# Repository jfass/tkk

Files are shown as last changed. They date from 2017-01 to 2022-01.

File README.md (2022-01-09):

# ten key keyboard

This is my ten key keyboard. I want to type and mouse anywhere, on any surface, and this seems like a necessary step. After I came up with the layout, someone pointed me towards the [asetniop](http://asetniop.com) layout, but by then this was stuck in my head. In any event, this is my first attempt at building my own keyboard, and I have absolutely no idea what I'm doing. This is based on TristanTrim's [asetniop-keyboard](https://github.com/TristanTrim/asetniop-keyboard), but obviously with two more keys.

Layout ... the bottom row are the physical keys. But, hold any key and it activates the virtual row corresponding to the greek letter in blue; tap any key while still holding, and you get the corresponding key on the virtual row. So, tapping the 't' key gives you a 't'. But holding the 't' key activates the gamma row, so if you then tap your left pinky (the physical 'a' key) you get a minus ('-') character. No idea whether this will allow graceful typing; gotta build it first!

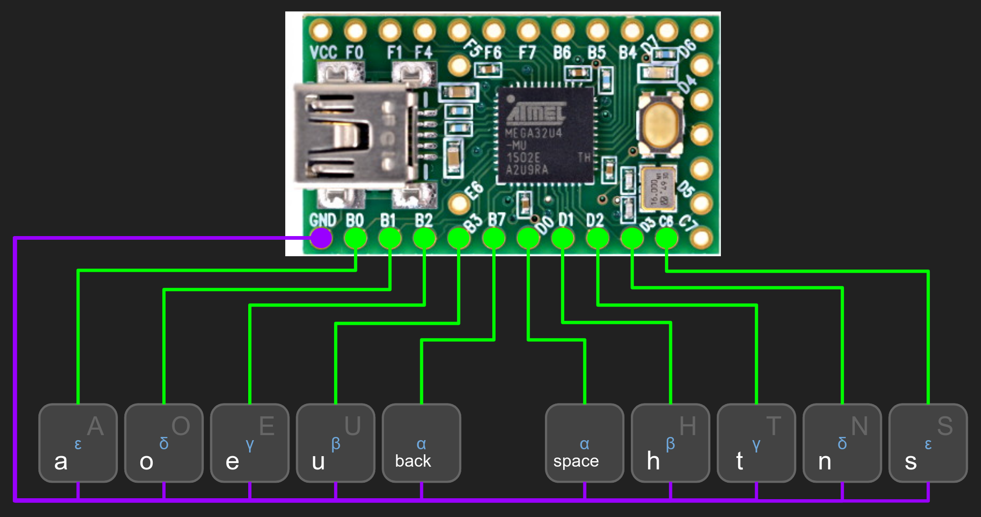
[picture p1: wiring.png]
Wiring
 ... with a Teensy 2.0.

... need to edit below here ...

## Installation
Keys are wired up directly to the pins D0 - D7. There are ways to do this that would save pins, but I like this method because it's easy, and I don't need the extra pins for anything.

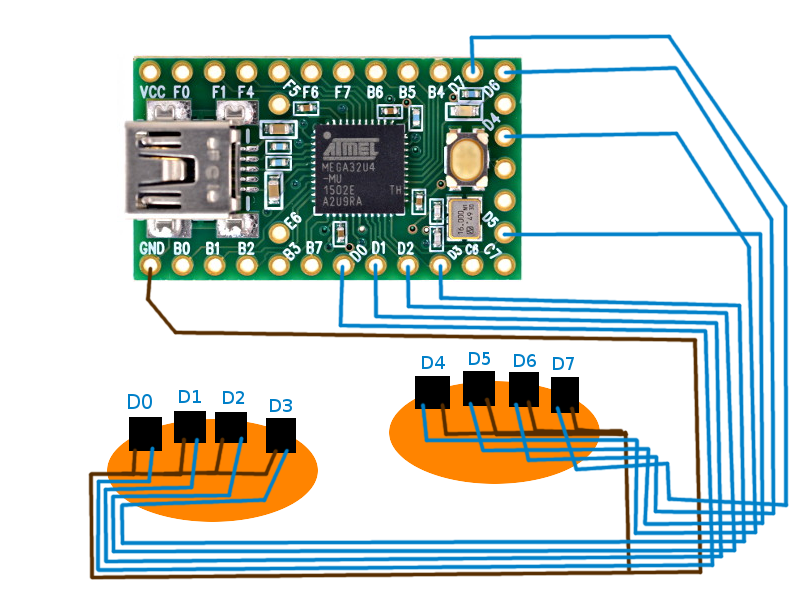
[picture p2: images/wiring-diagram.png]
wiring diagram


If you're on linux like me you may want to use the [bootloader](https://github.com/PaulStoffregen/teensy_loader_cli)

    sudo ./teensy_loader_cli/teensy_loader_cli --mcu=atmega32u4 asetniop.hex -w

Otherwise you'll have to flash the firmware some other way. Message me if you don't know how and I'll try to help you out.

## Bill of materials

 - [A teensyduino 2.0 board.](https://www.pjrc.com/store/teensy.html)
 - A 3D printed copy of each of the [.stl files.](https://github.com/TristanTrim/asetniop-keyboard/tree/master/printed_parts)
 - [8 Keyswitches](https://mechanicalkeyboards.com/shop/index.php?l=product_detail&p=708)
 - [8 Keycaps](http://www.wasdkeyboards.com/index.php/products/blank-keycap-singles/row-2-size-1x1-cherry-mx-keycap.html) (if you're not printing them)
 - wire and solder tools.
 - M3 nuts and bolts for the case.

## Typing guide

If you want to start learning about typing with this style of chorded keyboard, you can use the asetniop [online demo](http://asetniop.com/try/tablet/) to start learning asetniop in your web browser using your qwerty keyboard. This way you can find out what its like to type with a chorded keyboard without needing to do anything radical like building a keyboard.

There are a number of additions to the asetniop chords to expand this project into a more general keyboard. Also my keyboard only has eight keys, so doesn't use the thumbs at all. I'll explain below.

For the purpose of this guide I'm representing chords with a series of '.'s and '#'s. The '#'s represent a key being pressed down, and the '.'s a key left unpressed. Read from left to right the keys represented are the left pinky key through to the right pinky key.

### Numbers
The numbers all use .### on the left as somewhat of a prefix, and then follows a binary sequence from 0 to 9.

    .### .... : 0
    .### ...# : 1
    .### ..#. : 2
    .### ..## : 3
    .### .#.. : 4
    .### .#.# : 5
    .### .##. : 6
    .### .### : 7
    .### #... : 8
    .### #..# : 9

### Arrow keys
Like with the numbers the arrow keys use a 'prefix'. They all start with the 'w' key; ##..

    ##.. ...# : up
    ##.. ..## : down
    ##.. ..#. : left
    ##.. .#.. : right

### Non-alphanumeric
The non-alphanumeric keys were some of the first I wanted for interacting with my computer. The way the 'ctrl', 'shift', 'alt', and 'mod/window' keys work is that you press the chord, and then it is applied to the next chord that is pressed. For example, to get a '?' you would press #### ..#. and then press #... ...#

    #### ...# : ctrl
    #### ..#. : shift
    #### .#.. : alt
    #### #... : mod/window
    .... #### : space
    ...# #### : enter
    ###. .... : tab
    #### .... : esc

The rest of the keys may be a bit confusing, because I didn't add chords for anything that would normally be accessed by pressing shift+'some key'. So, for example, to use a '!' you need to press the chord for shift followed by the key for 1. because of this it's important to remember where all the symbols are on the qwerty keyboard. (assuming you want to use them.)

Of the rest of the keys, some of them may be in the original asetniop, and others I may have added or changed. I don't really remember which is which, sorry.

    .... ##.# : [
    .... #.## : ]
    #... ...# : /
    #... ..#. : \
    #... #### : `
    ..#. ..#. : -
    ..#. ..## : =
    
## Random nonsense

 - [x] Chord started before previous chord released separation. Now you can press ..#. ...., ..## ...., ..#. ... for "ere". Play around with it.
 - [ ] multibackspace: undo as many keypresses as were sent on the last chord release, for example if you type "ere" when you meant "r" backspace 3 times is useful.
 - [ ] Improved circuit design to use 3 rather than 5 wires to the keys. Then chinsy audio cables could be used!
 - [ ] abandon wired and write this on a bluetooth platform
 - [ ] macro functionality.
 - [ ] saving & dumping macros.
 - [ ] some kinda ml for separating chords, cause I type "ere" a lot, but not "sds" so much.

blah blah blah

I'd like to add the rest of the keys on a standard keyboard, and maybe some special function keys, but I'm not sure when I'll get around to it.

Further down the line I would like to experiment with adding joystick / mouse functionality, and building a wireless pair.

Or abandoning this and making a pair that maps the fingers onto a ternary, rather than binary, system. You know, for the 3 positions ^ 10 fingers = 59049 chords, rather than the 2 positions ^ 8 fingers = 256 chords availiable on my current system. If I assume 12 axes because the thumbs move in two axes so nicely that gives me: 3 positions ^ 12 axes = 531441. That's 3 positions ^ 6 axes = 729 chords on one hand! The trouble then would never be space, but figuring out how to organise all the chords. Ok, it would probably still be space at some point, because who wants to be stuck with a vocabulary of just over half a million. So lame right?

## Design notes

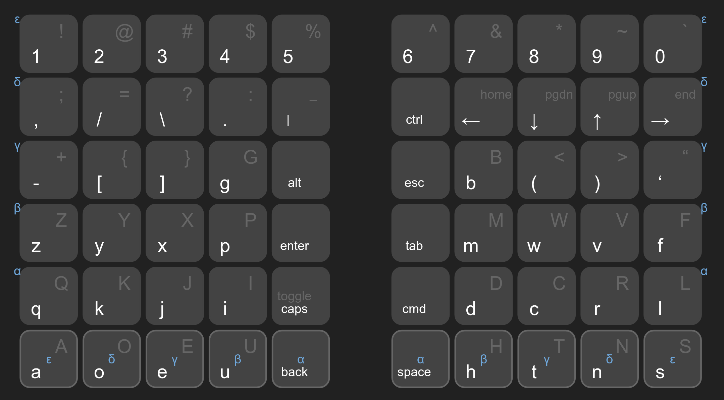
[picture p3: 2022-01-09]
layout.png

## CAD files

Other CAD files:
asetniop_render.blend

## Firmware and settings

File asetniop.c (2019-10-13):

/* This is the asetniop teensy code.
 * It implements a version of asetniop on a teensy
 * Based on the teensy keyboard example:
 *
 * Keyboard example with debug channel, for Teensy USB Development Board
 * http://www.pjrc.com/teensy/usb_keyboard.html
 * Copyright (c) 2008 PJRC.COM, LLC
 * 
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
 * THE SOFTWARE IS PROVIDED "AS IS", WITHOUT WARRANTY OF ANY KIND, EXPRESS OR
 * IMPLIED, INCLUDING BUT NOT LIMITED TO THE WARRANTIES OF MERCHANTABILITY,
 * FITNESS FOR A PARTICULAR PURPOSE AND NONINFRINGEMENT. IN NO EVENT SHALL THE
 * AUTHORS OR COPYRIGHT HOLDERS BE LIABLE FOR ANY CLAIM, DAMAGES OR OTHER
 * LIABILITY, WHETHER IN AN ACTION OF CONTRACT, TORT OR OTHERWISE, ARISING FROM,
 * OUT OF OR IN CONNECTION WITH THE SOFTWARE OR THE USE OR OTHER DEALINGS IN
 * THE SOFTWARE.
 */

#include <avr/io.h>
#include <avr/pgmspace.h>
#include <avr/interrupt.h>
#include <util/delay.h>
#include "usb_keyboard.h"

#define LED_CONFIG  (DDRD |= (1<<6))
#define LED_ON    (PORTD &= ~(1<<6))
#define LED_OFF    (PORTD |= (1<<6))
#define CPU_PRESCALE(n)  (CLKPR = 0x80, CLKPR = (n))


void zero(void);
void empty(void);
void normal(void);
void meta(void);
void arrow(void);
void page(void);

typedef void (*func)(void);
func keymap_func[6] = {zero, empty, normal, meta, arrow, page};
#define z 0
#define e 1
#define n 2
#define m 3
#define a 4
#define p 5


//128 64 32 16  8 4 2 1
uint8_t modifier_keys[4] =
    {KEY_CTRL,       KEY_SHIFT,       KEY_ALT,       KEY_GUI,       };
uint8_t modifier_key_numbers[4] =
    {128+64+32+16+1, 128+64+32+16+2, 128+64+32+16+4, 128+64+32+16+8,};
uint8_t modifier_chord_id;

// So I'm trying to make this array of chords kinda readable
// It's broken up into sixteen sections, each one has a set of all the
// chords formed with the same pattern on the left hand, and goes through
// the binary sequency of patterns for the right hand.
// That is to say, for each set the chord pattern goes like:
//    xx xx  .. .. ,  xx xx  .. .# ,  xx xx  .. #. ,  xx xx  .. ## ,
//    xx xx  .# .. ,  xx xx  .# .# ,  xx xx  .# #. ,  xx xx  .# ##  ,
//    xx xx  #. .. ,  xx xx  #. .# ,  xx xx  #. #. ,  xx xx  #. ## ,
//    xx xx  ## .. ,  xx xx  ## .# ,  xx xx  ## #. ,  xx xx  ## ##  ,
// Each entry consists of a function for how that chord should
// be interpreted, and a chord value that represents what that
// chord should send as a key to the computer.
// Like:    [function, value]
// So for example, the chord '.. ..  .# .#' represents the letter 'k'
// when that key is pressed, it is interpretted as a regular keypress
// so it gets the function 'normal' shorthanded to 'n'.
// Like:    [n,KEY_K        ] 
// All the empty space is to maintain a nice readable grid.


uint8_t key_map[256][2] = {
// .. ..    0
    {z,0            },{n,KEY_P        },{n,KEY_O        },{n,KEY_SEMICOLON},    // 0   1   2   3
    {n,KEY_I        },{n,KEY_K        },{n,KEY_L        },{e,0            },    // 4   5   6   7
    {n,KEY_N        },{n,KEY_M        },{n,KEY_U        },{n,KEY_RIGHT_BRACE},    // 8   9   10   11
    {n,KEY_H        },{n,KEY_LEFT_BRACE},{e,0           },{n,KEY_SPACE    },    // 12   13   14   15
// .. .#    16
    {n,KEY_T        },{n,KEY_BACKSPACE},{n,KEY_G        },{e,0            },    // 16   17   18   19
    {n,KEY_V        },{e,0            },{e,0            },{e,0            },    // 20   21   22   23
    {n,KEY_B        },{e,0            },{e,0            },{e,0            },    // 24   25   26   27
    {e,0            },{e,0            },{e,0            },{n,KEY_ENTER    },    // 28   29   30   31
// .. #.    32
    {n,KEY_E        },{n,KEY_QUOTE    },{n,KEY_MINUS    },{n,KEY_EQUAL    },    // 32   33   34   35
    {n,KEY_COMMA    },{e,0            },{e,0            },{e,0            },    // 36   37   38   39
    {n,KEY_Y        },{e,0            },{e,0            },{e,0            },    // 40   41   42   43
    {e,0            },{e,0            },{e,0            },{e,0            },    // 44   45   46   47
// .. ##    48
    {n,KEY_R        },{e,0            },{e,0            },{e,0            },    // 48   49   50   51
    {e,0            },{e,0            },{e,0            },{e,0            },    // 52   53   54   55
    {e,0            },{e,0            },{e,0            },{e,0            },    // 56   57   58   59
    {e,0            },{e,0            },{e,0            },{e,0            },    // 60   61   62   63
// .# ..    64
    {n,KEY_S        },{n,KEY_SPACE    },{n,KEY_PERIOD   },{e,0            },    // 64   65   66   67
    {n,KEY_Z        },{e,0            },{e,0            },{e,0            },    // 68   69   70   71
    {n,KEY_J        },{e,0            },{e,0            },{e,0            },    // 72   73   74   75
    {e,0            },{e,0            },{e,0            },{e,0            },    // 76   77   78   79
// .# .#    80
    {n,KEY_C        },{e,0            },{e,0            },{e,0            },    // 80   81   82   83
    {e,0            },{e,0            },{e,0            },{e,0            },    // 84   85   86   87
    {e,0            },{e,0            },{m, 0           },{e,0            },    // 88   89   90   91
    {e,0            },{e,0            },{e,0            },{e,0            },    // 92   93   94   95
// .# #.    96
    {n,KEY_D        },{e,0            },{e,0            },{e,0            },    // 96   97   98   99
    {e,0            },{e,0            },{e,0            },{e,0            },    // 100   101   102   103
    {e,0            },{e,0            },{e,0            },{e,0            },    // 104   105   106   107
    {e,0            },{e,0            },{e,0            },{e,0            },    // 108   109   110   111
// .# ##    112
    {n,KEY_0        },{n,KEY_1        },{n,KEY_2        },{n,KEY_3        },    // 112   113   114   115
    {n,KEY_4        },{n,KEY_5        },{n,KEY_6        },{n,KEY_7        },    // 116   117   118   119
    {n,KEY_8        },{n,KEY_9        },{e,0            },{e,0            },    // 120   121   122   123
    {e,0            },{e,0            },{e,0            },{e,0            },    // 124   125   126   127
// #. ..    128
    {n,KEY_A        },{n,KEY_SLASH    },{n,KEY_BACKSLASH},{e,0            },    // 128   129   130   131
    {e,0            },{e,0            },{e,0            },{e,0            },    // 132   133   134   135
    {n,KEY_Q        },{e,0            },{e,0            },{e,0            },    // 136   137   138   139
    {e,0            },{e,0            },{e,0            },{n,KEY_TILDE    },    // 140   141   142   143
// #. .#    144
    {n,KEY_F        },{e,0            },{e,0            },{e,0            },    // 144   145   146   147
    {e,0            },{e,0            },{e,0            },{e,0            },    // 148   149   150   151
    {e,0            },{e,0            },{e,0            },{e,0            },    // 152   153   154   155
    {e,0            },{e,0            },{e,0            },{e,0            },    // 156   157   158   159
// #. #.    160
    {n,KEY_X        },{e,0            },{e,0            },{e,0            },    // 160   161   162   163
    {e,0            },{n, 0           },{e,0            },{e,0            },    // 164   165   166   167
    {e,0            },{e,0            },{e,0            },{e,0            },    // 168   169   170   171
    {e,0            },{e,0            },{e,0            },{e,0            },    // 172   173   174   175
// #. ##    176
    {e,0            },{e,0            },{e,0            },{e,0            },    // 176   177   178   179
    {e,0            },{e,0            },{e,0            },{e,0            },    // 180   181   182   183
    {e,0            },{e,0            },{e,0            },{e,0            },    // 184   185   186   187
    {e,0            },{e,0            },{e,0            },{e,0            },    // 188   189   190   191
// ## ..    192
    {n,KEY_W        },{a,KEY_RIGHT    },{a,KEY_UP       },{e,0            },    // 192   193   194   195
    {a,KEY_DOWN     },{e,0            },{e,0            },{e,0            },    // 196   197   198   199
    {a,KEY_LEFT     },{e,0            },{e,0            },{e,0            },    // 200   201   202   203
    {e,0            },{e,0            },{e,0            },{e,0            },    // 204   205   206   207
// ## .#    208
    {e,0            },{e,0            },{e,0            },{e,0            },    // 208   209   210   211
    {e,0            },{e,0            },{e,0            },{e,0            },    // 212   213   214   215
    {e,0            },{e,0            },{e,0            },{e,0            },    // 216   217   218   219
    {e,0            },{e,0            },{e,0            },{e,0            },    // 220   221   222   223
// ## #.    224
    {n,KEY_TAB      },{p,KEY_END      },{p,KEY_PAGE_UP  },{e,0            },    // 224   225   226   227
    {p,KEY_PAGE_DOWN},{e,0            },{e,0            },{e,0            },    // 228   229   230   231
    {p,KEY_HOME     },{e,0            },{e,0            },{e,0            },    // 232   233   234   235
    {e,0            },{e,0            },{e,0            },{e,0            },    // 236   237   238   239
// ## ##    240  These are mostly all modifier keys. They are handled elsewhere, but still called with n
    {n,KEY_ESC      },{n,0            },{n,0            },{n,0            },    // 240   241   242   243
    {n,0            },{n,0            },{n,0            },{n,0            },    // 244   245   246   247
    {n,0            },{n,0            },{n,0            },{n,0            },    // 248   249   250   251
    {n,0            },{n,0            },{n,0            },{e,0            }     // 252   253   254   255
};

uint8_t realtime_index;
uint8_t realtime_map[2][4] =
{
    {KEY_LEFT       ,KEY_DOWN        ,KEY_UP          ,KEY_RIGHT       },
    {KEY_END        ,KEY_PAGE_DOWN   ,KEY_PAGE_UP     ,KEY_HOME        }
};

void read(void);
void keydown(void);
void keyup(void);
void keysend(void);

void dump_fifo(void);
void clear_fifo(void);
void debug_dump(void);
void realtime(void);
void keyhold(void);
void modpress(uint8_t modchord);
void send(int send_id);

uint8_t d, prev_d, mask, chord_id, prev_chord_id, pressed, modifier_pressed,timer;
uint8_t chord_keys[8];//={0,0,0,0,0,0,0,0};

uint8_t fifo_index;
uint16_t fifo[64][2];
uint16_t longest;
int chord_accept_numer = 1;
int chord_accept_denom = 2;

int debug_mode = 0;

uint8_t modkeys;
uint8_t modlocks;

#define keydown_delay  3000
#define min_press_detect  0
#define debounce_delay 300

int main(void)
{
  // Stuff from the original keyboard code for, like, being a keyboard and stuff.

  // set for 16 MHz clock
  CPU_PRESCALE(0);

  // Configure all port B and port D pins as inputs with pullup resistors.
  // See the "Using I/O Pins" page for details.
  // http://www.pjrc.com/teensy/pins.html
  DDRD = 0x00;
  PORTD = 0xFF;

  // Initialize the USB, and then wait for the host to set configuration.
  // If the Teensy is powered without a PC connected to the USB port,
  // this will wait forever.
  usb_init();
  while (!usb_configured()) /* wait */ ;

  // Wait an extra second for the PC's operating system to load drivers
  // and do whatever it does to actually be ready for input
  _delay_ms(1000);


  // And now for the main event!

  while (1) {
    read();
    keymap_func[  key_map[chord_id][0]  ]();
  }
}
///////////////////// we have lost cabin pressure.
//
//    if (((chord_id == 0) && (last_chord_id != 0)) || timer == timeout ) {
//        timer=timeout-timebetween;
//
//        mask = 1;
//        for (i=0; i<4; i++) {
//            if (modifier_key_numbers[i] == last_chord_id) {
//                modifier_pressed = 1;
//                if ((modifier_chord_id & mask) == 0 ) {
//                    modifier_chord_id += 1<<i;
//                }
//            }
//            mask = mask << 1;
//        }
//        if (modifier_pressed == 0) {
//            usb_keyboard_press(key_map[last_chord_id][1],modifier_chord_id);
//            modifier_chord_id = 0;
//        }
//        last_chord_id = 0;
//        modifier_pressed = 0;
//    }
//    if (chord_id > last_chord_id) {
//        last_chord_id = chord_id;
//    }
//
//    // now the current pins will be the previous, and
//    // wait a short delay so we're not highly sensitive
//    // to mechanical "bounce".
//    _delay_ms(2);
////////////////////////////// cabin pressure stabalized.


// keymap functions:

void zero(void){
  // When keys have been pressed and we are at zero
  // we know it's time to send those pressed keys!
  if(pressed){
    if(debug_mode){
      debug_dump();
    }
    dump_fifo();
  }
}
void empty(void){
  // As if we even care what happens when undefined
  // keys are pressed!
}
void normal(void){
  if(!pressed){
    fifo[fifo_index][0] = chord_id;
    pressed=1;
  }else{
    if(fifo[fifo_index][0] == chord_id){
      if(fifo[fifo_index][1] > keydown_delay){
        keyhold();
      }else{
        if(++fifo[fifo_index][1] > longest){
          longest = fifo[fifo_index][1];
        }
      }
    }else{
      fifo_index++;
      fifo[fifo_index][0] = chord_id;
    }
  }
}
void meta(void){
  while(1){
    read();
    if(chord_id != 90)
      break;
  }
  debug_mode = !debug_mode;
  if(debug_mode){
    usb_keyboard_press(KEY_D,2);
    usb_keyboard_press(KEY_E,2);
    usb_keyboard_press(KEY_B,2);
    usb_keyboard_press(KEY_U,2);
    usb_keyboard_press(KEY_G,2);
    usb_keyboard_press(KEY_ENTER,0);
  }else{
    usb_keyboard_press(KEY_B,2);
    usb_keyboard_press(KEY_A,2);
    usb_keyboard_press(KEY_C,2);
    usb_keyboard_press(KEY_K,2);
    usb_keyboard_press(KEY_SPACE,2);
    usb_keyboard_press(KEY_T,2);
    usb_keyboard_press(KEY_O,2);
    usb_keyboard_press(KEY_SPACE,2);
    usb_keyboard_press(KEY_N,2);
    usb_keyboard_press(KEY_O,2);
    usb_keyboard_press(KEY_R,2);
    usb_keyboard_press(KEY_M,2);
    usb_keyboard_press(KEY_A,2);
    usb_keyboard_press(KEY_L,2);
    usb_keyboard_press(KEY_SPACE,2);
    usb_keyboard_press(KEY_MINUS ,0);
    usb_keyboard_press(KEY_SPACE,2);
    usb_keyboard_press(KEY_N,2);
    usb_keyboard_press(KEY_O,2);
    usb_keyboard_press(KEY_T,2);
    usb_keyboard_press(KEY_H,2);
    usb_keyboard_press(KEY_I,2);
    usb_keyboard_press(KEY_N,2);
    usb_keyboard_press(KEY_G,2);
    usb_keyboard_press(KEY_SPACE,2);
    usb_keyboard_press(KEY_T,2);
    usb_keyboard_press(KEY_O,2);
    usb_keyboard_press(KEY_SPACE,2);
    usb_keyboard_press(KEY_S,2);
    usb_keyboard_press(KEY_E,2);
    usb_keyboard_press(KEY_E,2);
    usb_keyboard_press(KEY_SPACE,2);
    usb_keyboard_press(KEY_H,2);
    usb_keyboard_press(KEY_E,2);
    usb_keyboard_press(KEY_R,2);
    usb_keyboard_press(KEY_E,2);
    usb_keyboard_press(KEY_ENTER,0);
  }
}
void arrow(void){
  realtime_index = 0;
  realtime();
}
void page(void){
  realtime_index = 1;
  realtime();
}

// hardware functions:

void read(void){
  // read all port D pins
  d = PIND;
  int i=0;
  while(1){// debouncing loop
    prev_d = d;
    d = PIND;
    if(d==prev_d)
      i++;
    else
      i=0;
    if(i==debounce_delay)
      break;
  } 
  chord_id = ~d;
  mask = 1;// sweepy sweepy sweep my byte!
  for (int i=0; i<8; i++) {
    if ((d & mask) == 0)  {
              chord_keys[i] = 1;
          }
    mask = mask << 1;
  }
}
void keydown(void){
}
void keyup(void){
}
void keysend(void){
  usb_keyboard_press(key_map[chord_id][1],modifier_chord_id);
}

// cool functions that I like:
void debug_dump(void){
  usb_keyboard_press(KEY_C,1);            /////////// DEBUGING TOOL, PRINT BASED ON HOW MUCH IT"S PRESSED
  usb_keyboard_press(KEY_C,1);            /////////// DEBUGING TOOL, PRINT BASED ON HOW MUCH IT"S PRESSED
  usb_keyboard_press(KEY_ENTER,0);            /////////// DEBUGING TOOL, PRINT BASED ON HOW MUCH IT"S PRESSED
  usb_keyboard_press(KEY_SPACE,0);            /////////// DEBUGING TOOL, PRINT BASED ON HOW MUCH IT"S PRESSED
  usb_keyboard_press(KEY_COMMA,2);            /////////// DEBUGING TOOL, PRINT BASED ON HOW MUCH IT"S PRESSED
  usb_keyboard_press(KEY_3,0);            /////////// DEBUGING TOOL, PRINT BASED ON HOW MUCH IT"S PRESSED
  usb_keyboard_press(KEY_SPACE,0);            /////////// DEBUGING TOOL, PRINT BASED ON HOW MUCH IT"S PRESSED
  int accept_len = longest*chord_accept_numer/chord_accept_denom;
  for(int i=0; i<=accept_len/20; i++)
    usb_keyboard_press(KEY_EQUAL,0);      /////////// DEBUGING TOOL, PRINT BASED ON HOW MUCH IT"S PRESSED
  for(int i=0; i<=(longest-accept_len)/20; i++)
    usb_keyboard_press(KEY_MINUS,0);      /////////// DEBUGING TOOL, PRINT BASED ON HOW MUCH IT"S PRESSED
  usb_keyboard_press(KEY_C,1);            /////////// DEBUGING TOOL, PRINT BASED ON HOW MUCH IT"S PRESSED
  usb_keyboard_press(KEY_ENTER,0);            /////////// DEBUGING TOOL, PRINT BASED ON HOW MUCH IT"S PRESSED
  for(int i=0; i<=fifo_index; i++){
    if(fifo[i][1] > accept_len){// YES! SEND IT
      usb_keyboard_press(KEY_1,2);
      usb_keyboard_press(KEY_1,2);
      usb_keyboard_press(KEY_1,2);
    }else{  /// NOT ENOUGH SENDAGE
      usb_keyboard_press(KEY_SPACE,0);
      usb_keyboard_press(KEY_SPACE,0);
      usb_keyboard_press(KEY_SPACE,0);
    }
    send(fifo[i][0]);//// ACTUALLY SEND THE DAMNED KEYPRESS
    for(int j =0; j<fifo[i][1]/20;j++)  /////////// DEBUGING TOOL, PRINT BASED ON HOW MUCH IT"S PRESSED
      usb_keyboard_press(KEY_MINUS,0);      /////////// DEBUGING TOOL, PRINT BASED ON HOW MUCH IT"S PRESSED
    usb_keyboard_press(KEY_C,1);            /////////// DEBUGING TOOL, PRINT BASED ON HOW MUCH IT"S PRESSED
    usb_keyboard_press(KEY_ENTER,0);            /////////// DEBUGING TOOL, PRINT BASED ON HOW MUCH IT"S PRESSED
  }
  usb_keyboard_press(KEY_ENTER,0);            /////////// DEBUGING TOOL, PRINT BASED ON HOW MUCH IT"S PRESSED
}
void dump_fifo(void){
  int accept_len = longest*chord_accept_numer/chord_accept_denom;
  for(int i=0; i<=fifo_index; i++){
    if(fifo[i][1] > accept_len){// YES! SEND IT
      send(fifo[i][0]);
    }
    fifo[i][1]=0;
  }
  longest = min_press_detect*2;
  pressed = 0;
  fifo_index = 0;
}
void clear_fifo(void){
  for(int i=0; i<=fifo_index; i++){
    fifo[i][1]=0;
  }
  longest = min_press_detect*2;
  pressed = 0;
  fifo_index = 0;
}
void send(int send_id){
  // send_id is the id of the chord we're gonna send.
  if(send_id>240&&send_id!=255){ // If it's a modifier chord
    if(debug_mode){
      usb_keyboard_press(KEY_M,2);
      usb_keyboard_press(KEY_O,2);
      usb_keyboard_press(KEY_D,2);
    }else{ // Don't send modifier in debug mode. It does things. Bad things.
      modpress(send_id);
    }
  }else if(send_id == 165){// 165 is #.#. .#.# and the clear mod key.
    if(debug_mode){
      usb_keyboard_press(KEY_N,2);
      usb_keyboard_press(KEY_O,2);
      usb_keyboard_press(KEY_M,2);
      usb_keyboard_press(KEY_O,2);
      usb_keyboard_press(KEY_D,2);
    }
    modlocks =  0;
    modkeys = 0;
  }else{
    usb_keyboard_press(key_map[send_id][1], modkeys|modlocks);
    modkeys = 0;
  }
}
void modpress(uint8_t modchord){
  uint8_t mod = modchord & 15;
  modlocks |= mod & modkeys;
  modkeys |= mod;
}
void realtime(void){
  for(int i=0;i<500;i++){
    prev_chord_id = chord_id;
    read();
    if(chord_id != prev_chord_id)
      return;
  }
  clear_fifo();
  prev_chord_id = chord_id;// I'm in the middle of writing this. REFER TO THE DIAGRAMS!!!
  mask = 8;
  for(int i=0;i<4;i++){
    if(chord_id & mask){
      keyboard_keys[i] = realtime_map[realtime_index][i];
    }
    mask >>= 1;
  }
  usb_keyboard_send();
  while(1){
    read();
    if(chord_id & 0xF0){
      if(chord_id != prev_chord_id){
        mask = 8;
        for(int i=0;i<4;i++){
          if(chord_id & mask){
             keyboard_keys[i] = realtime_map[realtime_index][i];
          }else{
             keyboard_keys[i] = 0;
          }
          mask >>= 1;
        }
      }
      usb_keyboard_send();
      prev_chord_id = chord_id;
    }else{
      break;
    }
  }
  for(int i=0;i<4;i++){
    keyboard_keys[i] = 0;
  }
  usb_keyboard_send();
}

void keyhold(void){
  clear_fifo();
  keyboard_keys[0] = key_map[chord_id][1];
  usb_keyboard_send();
  while(chord_id){
    read();
  }
  keyboard_keys[0] = 0;
  usb_keyboard_send();
}

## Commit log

2016-04-13 Printed parts, and old weird readme.
    [miscolouredEggCase.blend, miscolouredEggCaseBottom.stl, miscolouredEggCaseBottomMirror.stl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]
2016-09-24 Update README.md
    Insane ramblings of a system with two keys on each finger, one pressed by moving up, the other by moving down.
    I guess it may be better to do a two key system where each finger can press the two keys symotaineously, but I guess I'll leave that that would give 2^20=1048576 here in the commit. It's only twice t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
2017-01-28 3d printed parts are also part of the bom
2019-01-06 added stupid time between thing. Its all buggy, but whatever, I'm about to do a complete rewrite. Never use this commit!
    [asetniop.c]
2019-01-09 Stuffs still kinda buggy, but, I have the realtime direction keys working, and I have keyholds, which are a little weird, cause when you press a key down it waits on the asetniop, before sending the 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
    [asetniop.c]
2022-01-09 swapped in layout and wiring images, started to edit README
    [miscolouredEggCase.blend, miscolouredEggCaseBottom.stl, miscolouredEggCaseBottomMirror.stl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]
